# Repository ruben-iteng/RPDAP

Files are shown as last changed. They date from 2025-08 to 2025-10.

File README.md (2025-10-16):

<div align="center">

# RPDAP

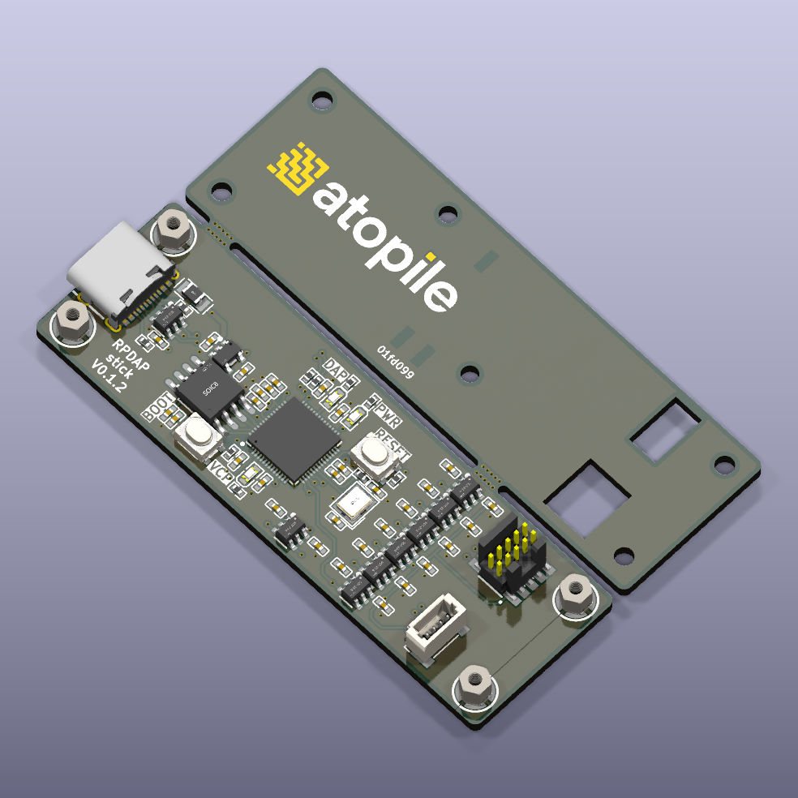
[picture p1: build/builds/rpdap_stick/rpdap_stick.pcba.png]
3D render

<br/>

CMSIS-DAP debugger hardware based on a Raspberry Pi RP2040 microcontroller.

   

</div>

## About

This project contains the hardware designs for a RP2040 based CMSIS-DAP debugger running the [free-dap](https://github.com/ruben-iteng/free-dap) firmware.

This project is build with [atopile](https://atopile.io).

### Features

- USB interface (data and power)
- status LEDs for VCP (Virtual COM Port), DAP status, and power.
- level shifted target interface (SWD, UART)
  - 1.2-5.5V target logic voltage

#### Layouts

There are various layouts and standalone boards available:

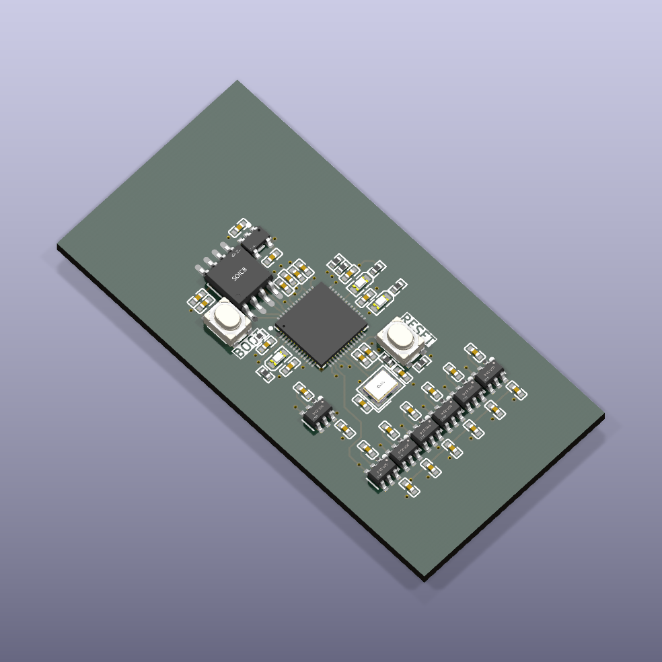
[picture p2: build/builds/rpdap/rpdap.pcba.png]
Basic layout
|   | Stick shaped layout  |
|---|---|
| Basic layout without connectors (for inclusion in your own design/PCBA) | Standalone stick shaped layout with female USB Type-C, Cortex-M debug header and 4-pin JST-SH UART connector. All inside a PCB enclosure. |
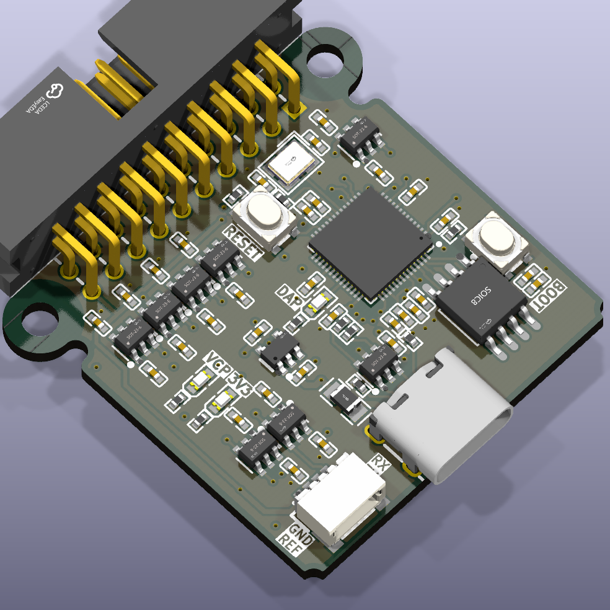
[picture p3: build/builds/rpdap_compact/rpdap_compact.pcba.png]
RPDAP Compact board
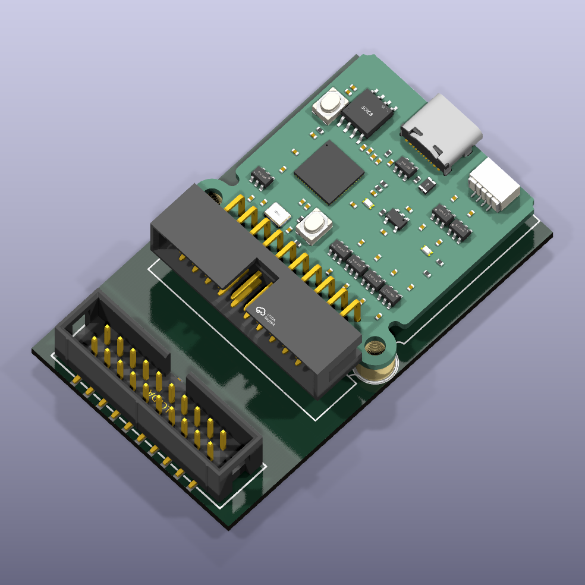
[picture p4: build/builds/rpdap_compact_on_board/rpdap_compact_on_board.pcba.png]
JLink Base Compact compatible "footprint"
|    |  |
| Standalone RPDAP Compact board (JLink Base Compact compatible board shape) |  JLink Base Compact compatible "footprint" (for using as build-in debugger/programmer) |

### Firmware

The firmware for the debugger is available in the [free-dap](https://github.com/ruben-iteng/free-dap/releases/latest) repository.
Follow this standard RP2040 flashing procedure to flash the firmware.

### Enclosures

This RPDAP Stick has a build in enclosure in the design (part of the PCB), and the RPDAP Compact board has a [3D printable enclosure](./cad/README.md) available.

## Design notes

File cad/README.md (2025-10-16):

# CAD files

This directory contains the CAD files for an enclosure for the RPDAP compact board, including a DIN rail mount.

The enclosure is designed to be FDM 3D printed, and uses transparent filament for the light guides.
The following screws were used to put everything together:

- 2x M2.9X8 self tapping screws for plastic
- [Aliexpress part](https://nl.aliexpress.com/item/1005004102674045.html)

Optionally you can add these silicone feet at the bottom of the enclosure which will also give it a snug fit into the DIN rail mount.

- 1mm thick, 6mm diameter silicone feet
- [Aliexpress part](https://nl.aliexpress.com/item/1005008384264974.html)

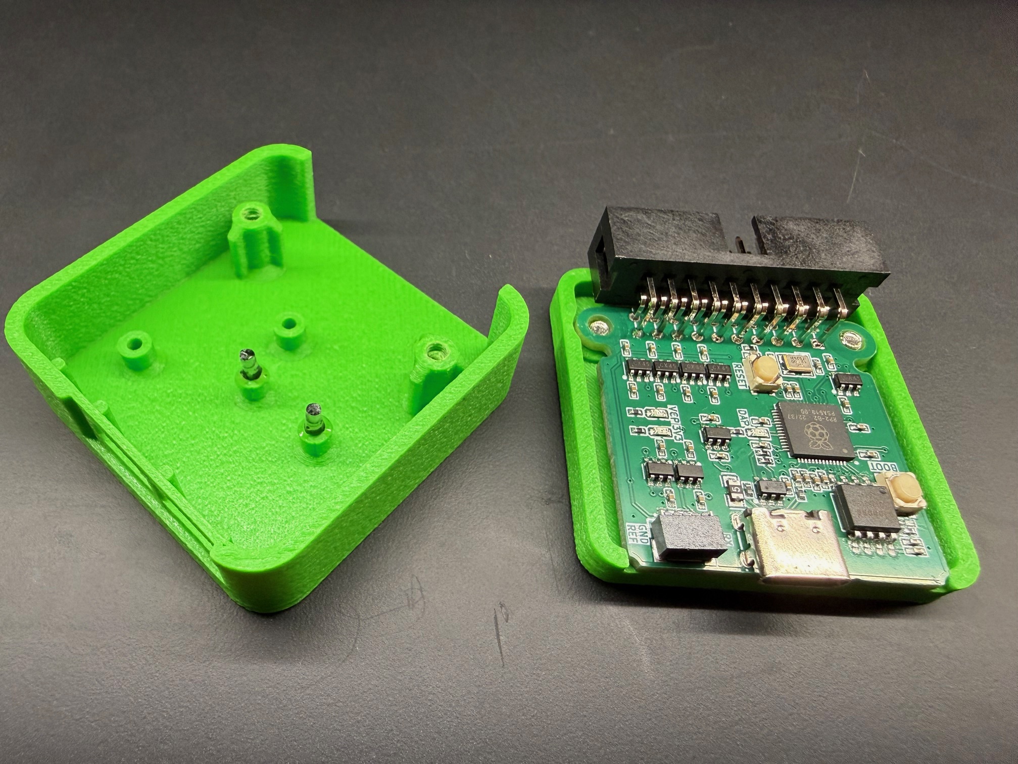
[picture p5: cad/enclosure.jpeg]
Enclosure

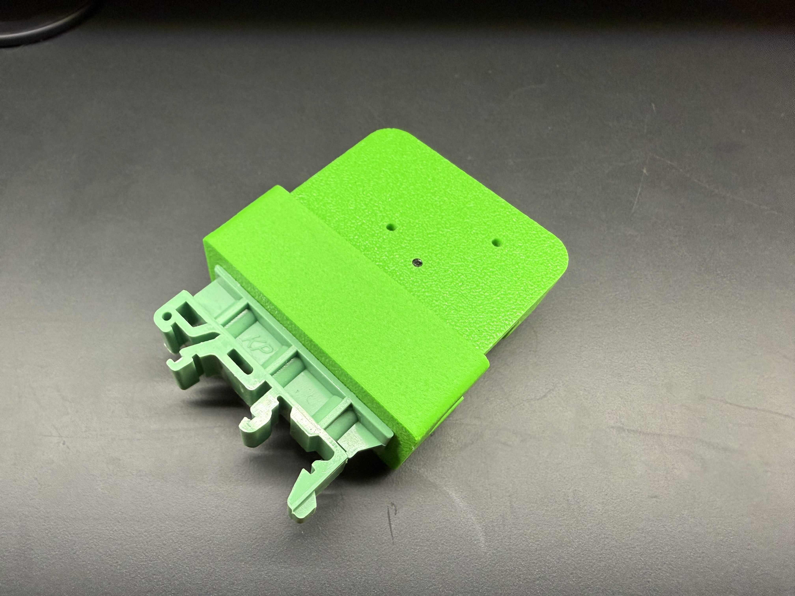
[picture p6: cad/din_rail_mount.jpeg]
DIN rail mount


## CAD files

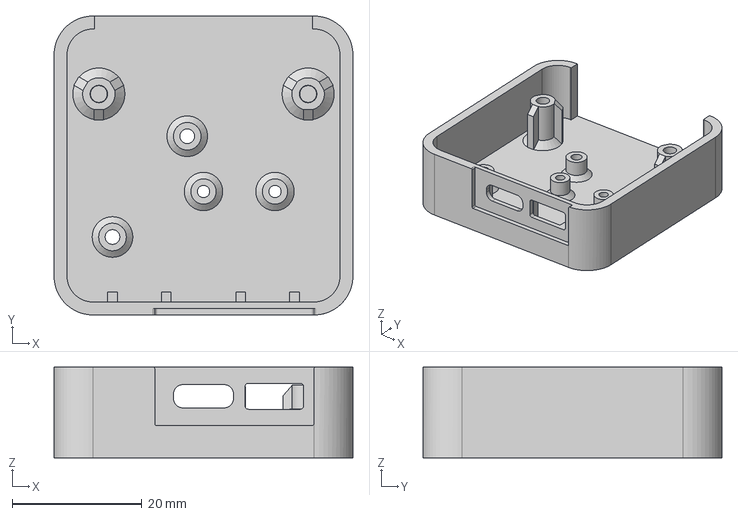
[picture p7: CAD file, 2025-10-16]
cad/box.step
46.0 x 46.0 x 14.0 mm

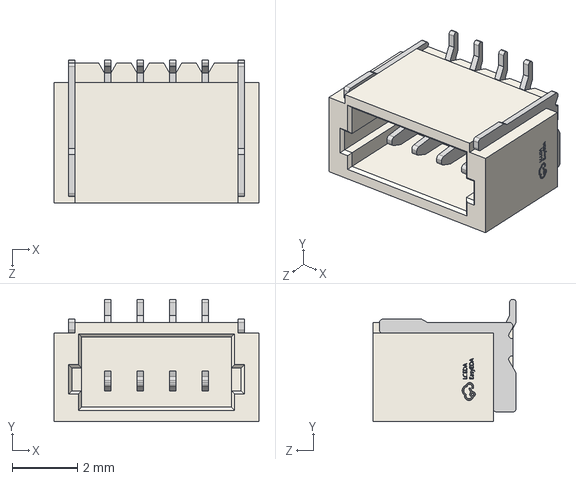
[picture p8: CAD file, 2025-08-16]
parts/HCTL_HC_1_0_4PLT/CONN-SMD_4P-P1.00_HC-1.0-4PLT.step
6.30 x 3.76 x 4.40 mm

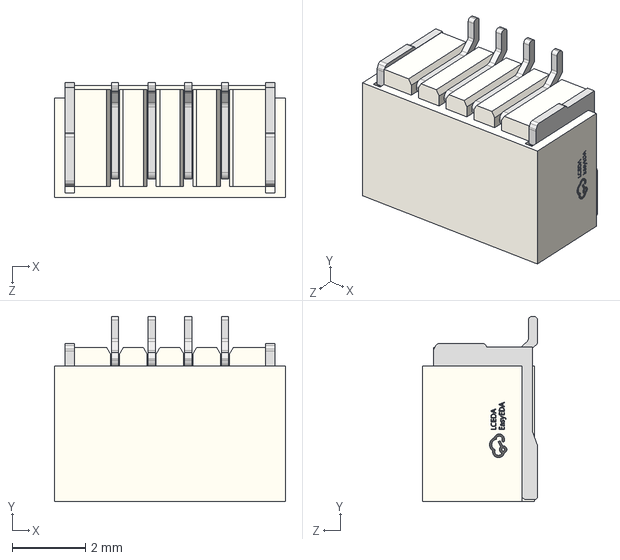
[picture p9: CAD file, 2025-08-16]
parts/HCTL_HC_1_0_4PWT_B_HW/CONN-SMD_4P-P1.00_HCTL_HC-1.0-4PWT.step
6.30 x 5.05 x 3.14 mm

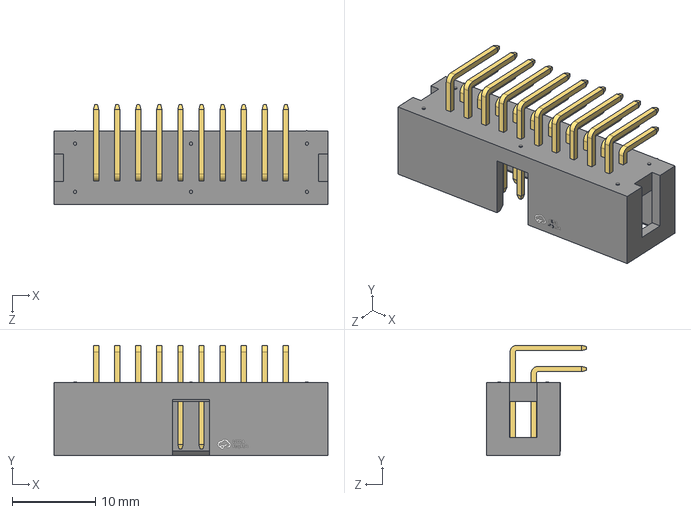
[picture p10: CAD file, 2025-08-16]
parts/Megastar_ZX_IDC2_54_2_10PWZ/IDC-TH_20P-P2.54_ZX-IDC2.54-2-10PWZ.STEP
33.0 x 13.3 x 12.0 mm

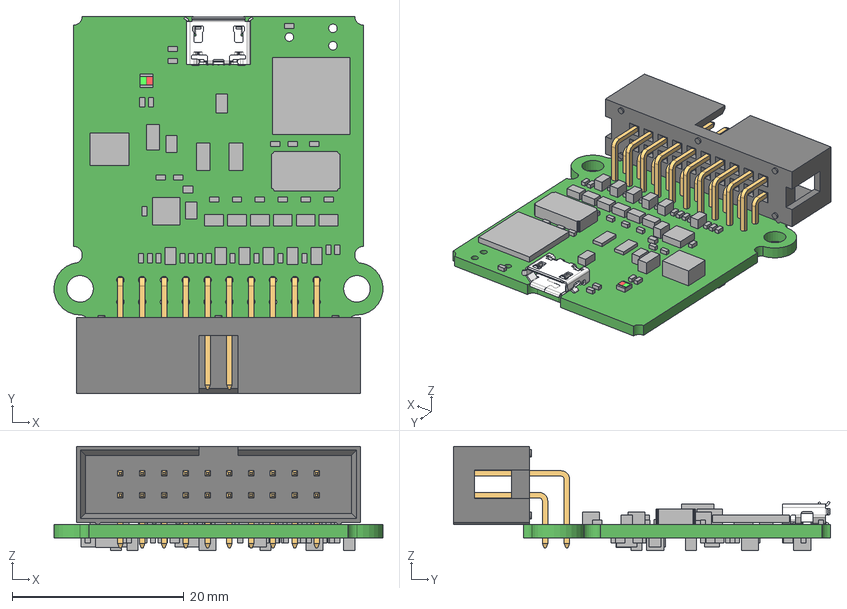
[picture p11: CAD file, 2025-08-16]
parts/RPDAP_Compact/J_Link_Compact_V1.0A.step
38.3 x 44.0 x 12.2 mm

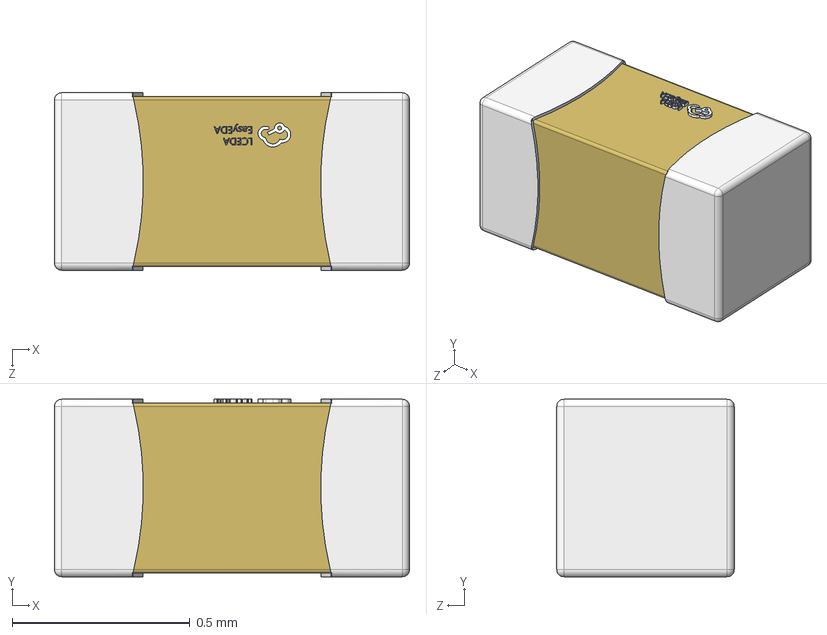
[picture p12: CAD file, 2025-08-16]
parts/Samsung_Electro_Mechanics_CL05A225KO5NQNC/C0402_L1.0-W0.5-H0.5.step
1.00 x 0.5 x 0.5 mm

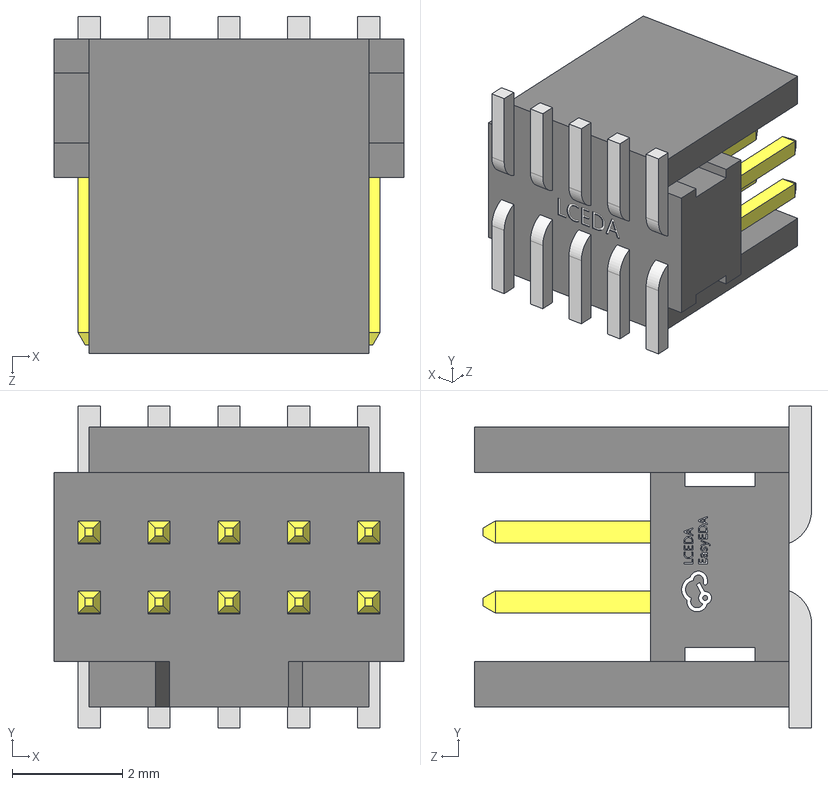
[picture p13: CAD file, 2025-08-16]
parts/Samtec_FTSH_105_01_L_DV_K_TR/CONN-SMD_FTSH-105-01-L-DV-K-TR.step
6.35 x 5.84 x 6.12 mm

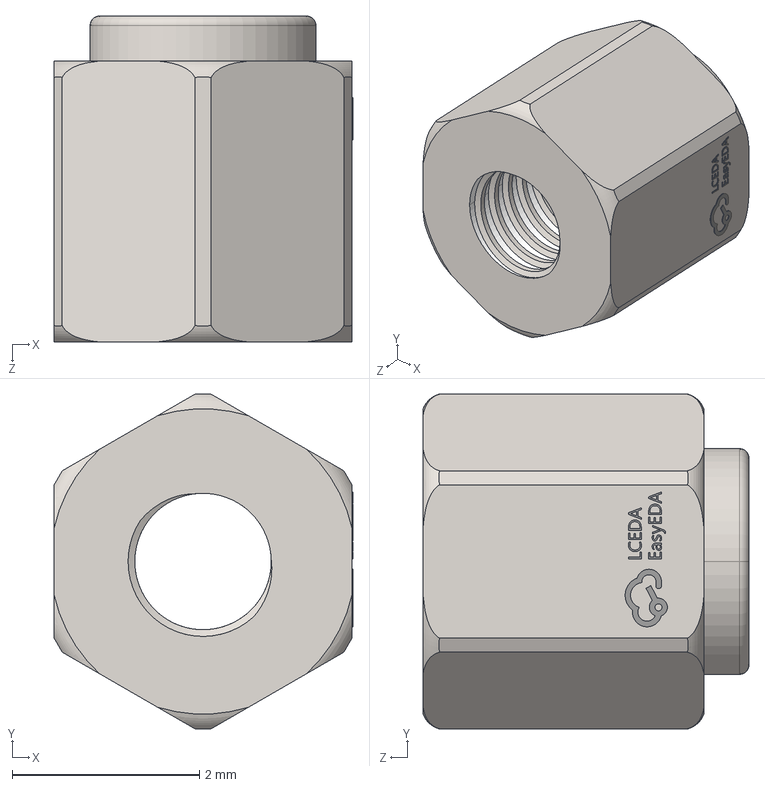
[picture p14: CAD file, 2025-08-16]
parts/Sinhoo_SMTSO1630MTJ/SMD_BD3.2-D2.4.STEP
3.19 x 3.57 x 3.48 mm

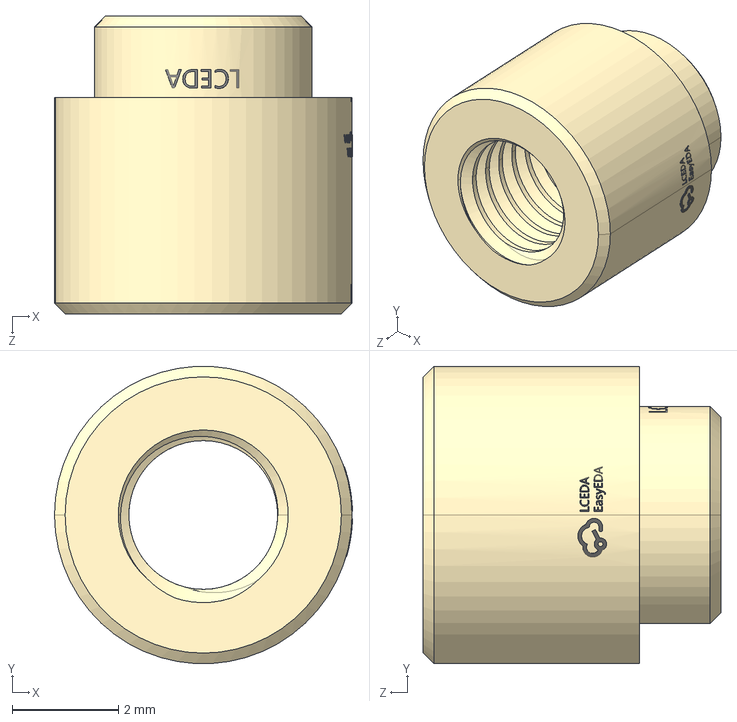
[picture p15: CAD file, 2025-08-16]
parts/Sinhoo_SMTSO2530CTJ/SMD_BD5.6-L5.6-W5.6-D4.1.step
5.61 x 5.59 x 5.60 mm

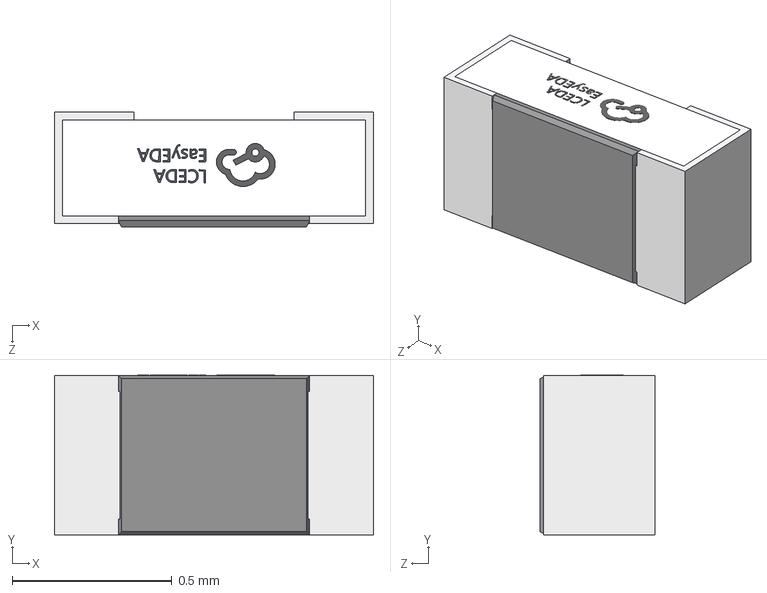
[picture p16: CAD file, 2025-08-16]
parts/UNI_ROYAL_0402WGF270JTCE/R0402_L1.0-W0.5-H0.4.step
1.00 x 0.501 x 0.36 mm

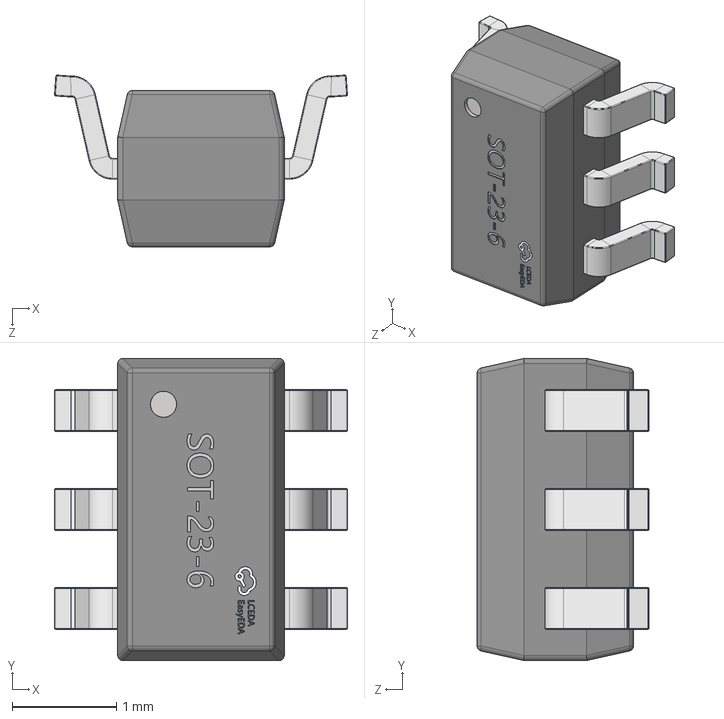
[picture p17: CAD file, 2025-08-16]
parts/Wuxi_I_core_Elec_AiP74LVC1T45GB236_TR/SOT-23-6_L2.9-W1.6-H1.5-LS2.8-P0.95.step
2.81 x 2.90 x 1.65 mm

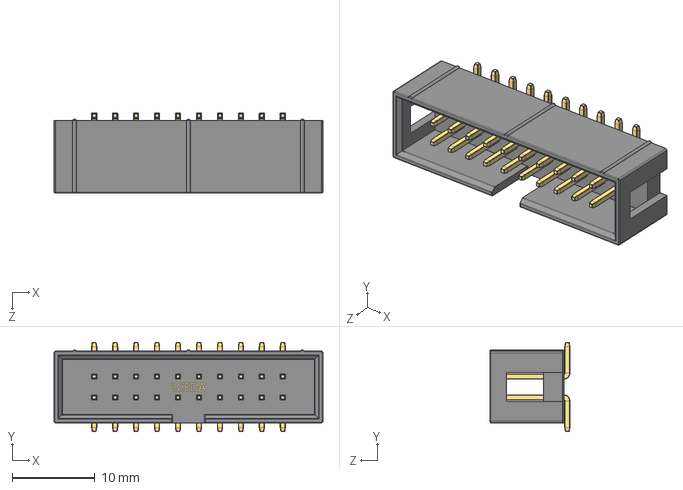
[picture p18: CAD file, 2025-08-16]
parts/XFCN_BH254VS_20P/CONN-SMD_IDC2.54-LS-2x10P.step
32.6 x 10.8 x 9.69 mm

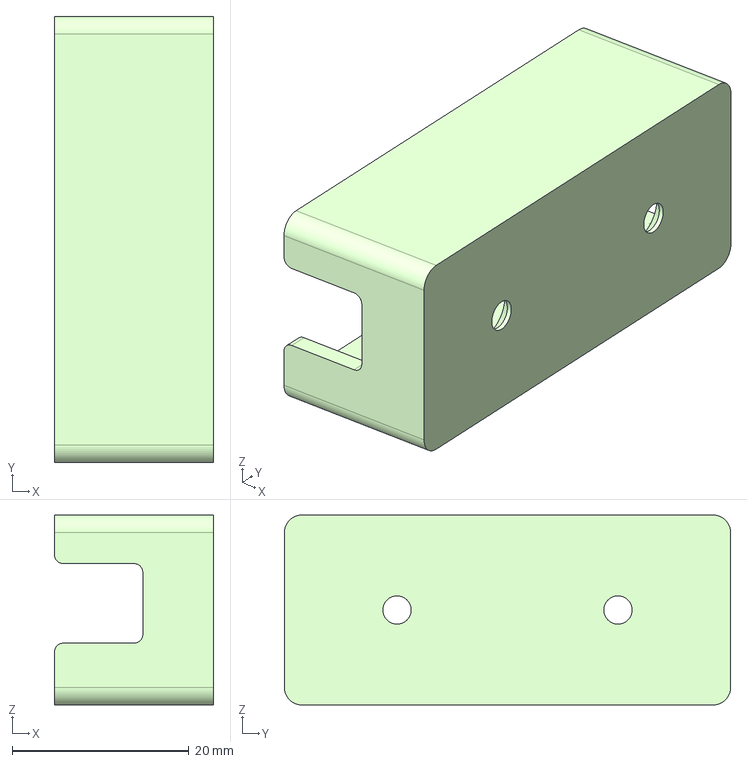
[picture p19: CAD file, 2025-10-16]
cad/mount.step
18.0 x 50.5 x 21.5 mm

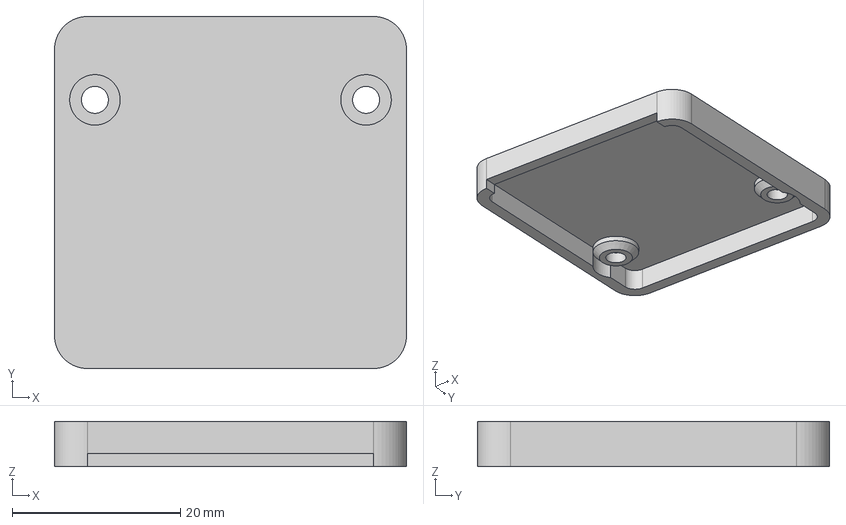
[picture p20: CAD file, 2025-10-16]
cad/lid.step
41.8 x 41.8 x 5.40 mm

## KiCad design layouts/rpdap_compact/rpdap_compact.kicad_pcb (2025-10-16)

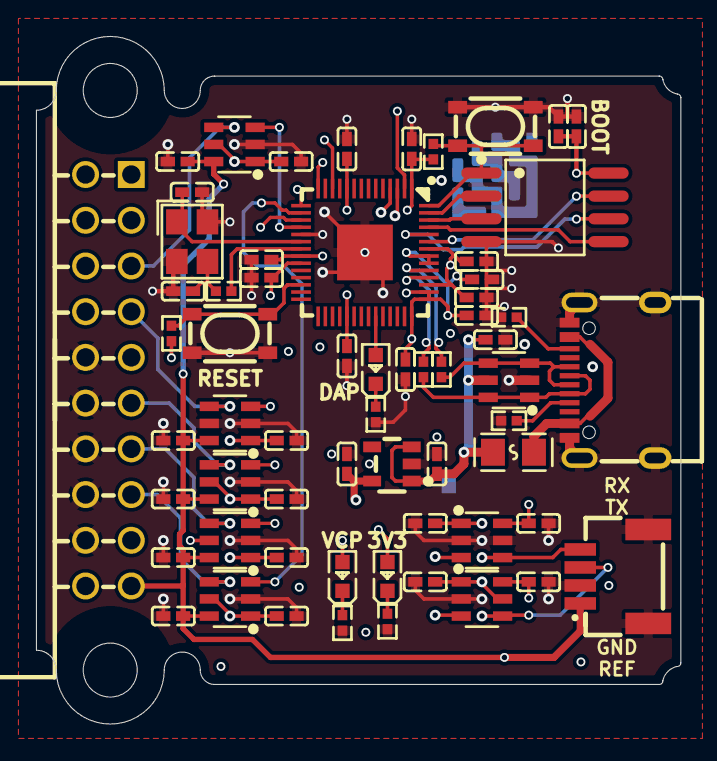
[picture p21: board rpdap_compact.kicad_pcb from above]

Board: 4 copper layers, 35.8 x 38.2 mm, 63 parts (0 on the bottom side), 42 nets.

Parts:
C1, C2, C3, C4, C5, C6, C7, C8, C9, C10, C11, C12, C13, C14, C17, C18, C22, C23, C24, C25, C26, C27, C29, C31, C32, C33: 100nF ±10% 16V X7R; C0402
C16, C21, C28: 2.2µF ±10% 16V X5R; C0402
C19, C20: 15pF ±5% 50V C0G; C0402
CN1: CONN-SMD_4P-P1.00_HCTL_HC-1.0-4PWT
D1: SOT-23-6_L2.9-W1.6-P0.95-LS2.8-BL
F1: F0805
J1: IDC-TH_20P-P2.54_ZX-IDC2.54-2-10PWZ
LED1, LED2, LED3: LED0603-RD
LOGO1: atopile_Logo_25x6mm
R1, R4: 1kΩ ±1% 62.5mW; R0402
R2, R3, R5, R6: 10kΩ ±1% 62.5mW; R0402
R7, R8: 27Ω ±1% 62.5mW; R0402
R9, R10: 5.1kΩ ±1% 62.5mW; R0402
SW1, SW2: KEY-SMD_4P-L4.2-W3.2-P2.20-LS4.6
U1, U3, U4, U5, U6, U7, U8: SOT-23-6_L2.9-W1.6-P0.95-LS2.8-BL
U2: SOT-23-5_L2.9-W1.6-P0.95-LS2.8-BR
U9: LQFN-56_L7.0-W7.0-P0.4-EP
U10: SOIC-8_L5.3-W5.3-P1.27-LS8.0-BL
USB1: USB-C-SMD_TYPE-C-6PIN-2MD-073
X1: CRYSTAL-SMD_4P-L3.2-W2.5-BL

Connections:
3V3: C2.1, C3.1, C5.1, C7.1, C9.1, C11.1, C13.1, C21.1, C22.1, C23.1, C24.1, C25.1, C26.1, C27.1, C28.1, C29.1, C32.1, LED1.2, R3.2, R6.2, U1.1, U2.5, U3.1, U3.5, U4.1, U5.1, U5.5, U6.1, U6.5, U7.1, U7.5, U8.1, U9.1, U9.10, U9.22, U9.33, U9.42, U9.43, U9.44, U9.48, U9.49, U10.8
DIR: U1.5, U9.12
GND: C1.2, C2.2, C3.2, C4.2, C5.2, C6.2, C7.2, C8.2, C9.2, C10.2, C11.2, C12.2, C13.2, C14.2, C16.2, C17.2, C18.2, C19.2, C20.2, C21.2, C22.2, C23.2, C24.2, C25.2, C26.2, C27.2, C28.2, C29.2, C31.2, C32.2, C33.2, CN1.2, CN1.5, CN1.6, D1.2, J1.10, J1.12, J1.14, J1.16, J1.18, R1.2, R2.2, R5.1, R9.2, R10.2, SW1.3, SW1.4, SW2.3, SW2.4, U1.2, U2.2, U3.2, U4.2, U4.5, U5.2, U6.2, U7.2, U8.2, U8.5, U9.19, U9.57, U10.4, USB1.1, USB1.12, USB1.13, USB1.14, USB1.15, USB1.16, X1.2, X1.4
K: LED2.1, R5.2
RUN: R6.1, SW2.1, SW2.2, U9.26
TCK_SWCLK: J1.11, U3.4
TDI: J1.15, U6.4
TDO_SWO: J1.7, U4.4
TMS_DIO: J1.13, U1.4
Vbus_fused: C1.1, C31.1, D1.5, F1.2, J1.1, U2.1, U2.3
XIN: C19.1, U9.20, X1.1
XOUT: R4.2, U9.21
_core_regulator_out_power-VCC: C16.1, C17.1, C18.1, U9.23, U9.45, U9.50
anode: LED3.2, U9.4
cc[0]-line: R9.1, USB1.4
cc[1]-line: R10.1, USB1.10
chip_select: R3.1, SW1.1, SW1.2, U9.56, U10.1
clock: U9.52, U10.6
data_0: U9.53, U10.5
data_1: U9.55, U10.2
data_2: U9.54, U10.3
data_3: U9.51, U10.7
footprint-cathode-0: LED1.1, R1.1
footprint-cathode-1: LED3.1, R2.1
gpio[11]-A: U3.3, U9.14
gpio[12]-A: U1.3, U9.15
gpio[13]-A: U6.3, U9.16
gpio[14]-A: U4.3, U9.17
gpio[15]-A: U5.3, U9.18
input-A: LED2.2, U9.37
input-USB_D_N: D1.1, D1.6, R8.1, USB1.5, USB1.7
input-USB_D_P: D1.3, D1.4, R7.1, USB1.6, USB1.8
mcu-uart-RX: U8.3, U9.3
mcu-uart-TX: U7.3, U9.2
nRESET: J1.5, U5.4
output: C20.1, R4.1, X1.3
output-USB_D_N: R8.2, U9.46
output-USB_D_P: R7.2, U9.47
power_vbus-VCC: F1.1, USB1.2, USB1.11
reference-VCC: C4.1, C6.1, C8.1, C10.1, C12.1, C14.1, C33.1, CN1.1, J1.19, U1.6, U3.6, U4.6, U5.6, U6.6, U7.6, U8.6
uart_connector-uart-RX: CN1.4, U8.4
uart_connector-uart-TX: CN1.3, U7.4

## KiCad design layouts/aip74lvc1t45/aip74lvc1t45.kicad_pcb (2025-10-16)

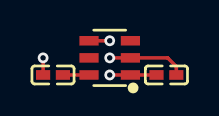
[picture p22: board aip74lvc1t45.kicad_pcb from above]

Board: 2 copper layers, 3 parts (0 on the bottom side), 3 nets.

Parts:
C1, C2: 100nF ±10% 16V X7R; C0402
U1: SOT-23-6_L2.9-W1.6-P0.95-LS2.8-BL

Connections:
GND: C1.2, C2.2, U1.2
power_a-VCC: C1.1, U1.1
power_b-VCC: C2.1, U1.6

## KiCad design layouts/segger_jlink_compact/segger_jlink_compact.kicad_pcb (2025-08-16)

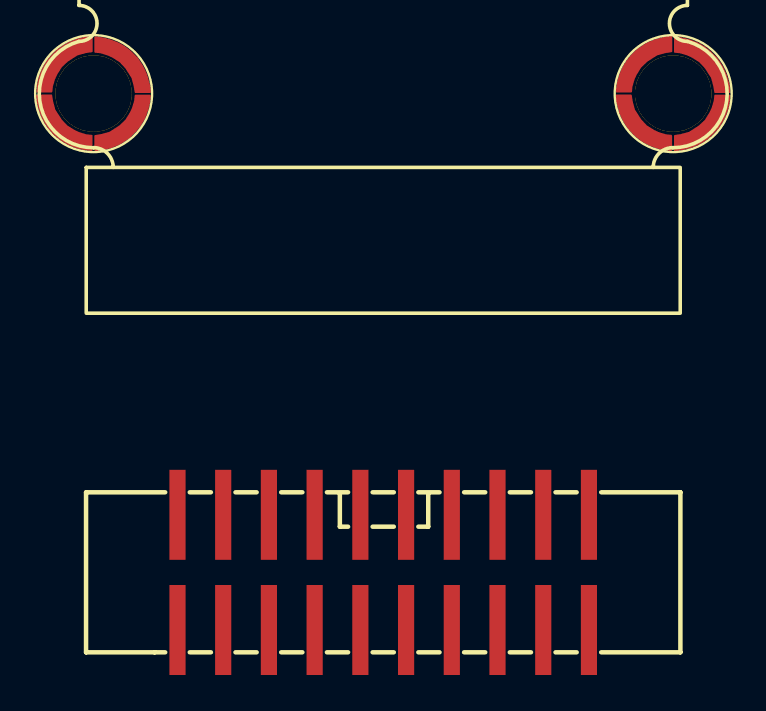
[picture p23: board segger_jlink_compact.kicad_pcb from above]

Board: 2 copper layers, 4 parts (0 on the bottom side), 3 nets, no tracks yet.

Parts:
H1, H2: SMD_BD5.6-L5.6-W5.6-D4.1
J1: CONN-SMD_20P-P2.54_BH-00019
MOD1: SEGGER_JLink_Compact

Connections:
gnd: J1.4, J1.6, J1.8, J1.10, J1.12
standoff[0]-contact: H1.1, H1.2, H1.3, H1.4
standoff[1]-contact: H2.1, H2.2, H2.3, H2.4

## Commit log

2022-12-30 Initial commit
    Strip down SSO from Ruben.
    Replace references with placeholders.
    Fix some typos etc.
    [main.kicad_pcb, main.kicad_sch]
2022-12-30 gitignore: More generic kicad filter
2022-12-30 gitignore: filter .local
2024-01-29 Update to newest faebryk & Improve
    Improve boilerplate & examples.
    Update & improvove readme & installation instructions.
    Add kicad empty files (with lcsc & logo lib).
    Make appropriate folder structure.
    [main.kicad_pcb, main.kicad_sch]
2024-08-25 Init repository
    [main.kicad_pcb]
2024-10-15 Add: basic design
    [main.kicad_pcb]
2025-08-16 Merge pull request #1 from ruben-iteng/feature/upgrade_to_ato_0_11_x
    Update to ato 0.11.x
    [C0402_L1.0-W0.5-H0.5.step, CONN-SMD_4P-P1.00_HC-1.0-4PLT.step, CONN-SMD_4P-P1.00_HCTL_HC-1.0-4PWT.step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]
2025-10-16 fix: Update deps, swapped pinout (#2)
    * rebuild with upstream rp2040 fixes. move header .25mm to the right. center dap-LED
    * fix workflow triggers
    * fix swapped jlink connector pinout + update deps
    * pin atopile workflow version to v1.x.x
    [C0402_L1.0-W0.5-H0.5.step, R0402_L1.0-W0.5-H0.4.step, aip74lvc1t45.kicad_pcb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]
2025-10-16 feat(3D): Add enclosure CAD files (#3)
    [box.step, lid.step, mount.step]

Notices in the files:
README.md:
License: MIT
